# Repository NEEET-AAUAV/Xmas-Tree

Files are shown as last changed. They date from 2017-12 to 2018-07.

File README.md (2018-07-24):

# :christmas_tree: :santa: :christmas_tree: DETI X-mas Tree :christmas_tree: :santa: :christmas_tree:

A **simple** (yet rather cool!) Christmas Tree using LEDs and Printed Circuit Boards.

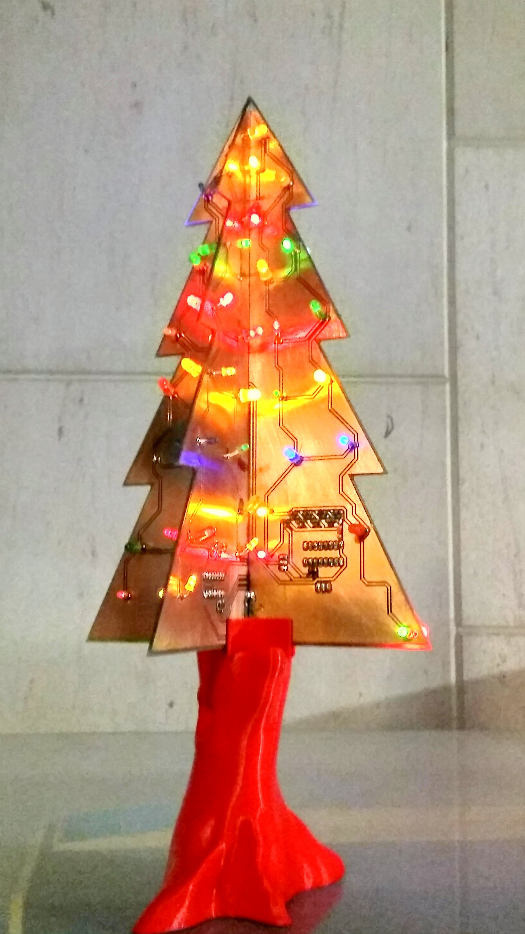
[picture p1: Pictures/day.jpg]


## :gift: List of Material
:snowflake: 64 (or 128) LEDs (_preferably 5mm LEDs_)  
:snowflake: 1 Arduino Nano  
:snowflake: 24 BC557  
:snowflake: 4 JHC138 (or 74HCT138)  
:snowflake: SMD Resistors  
:snowflake: Double Layer Printed Circuit Boards  

## :triangular_ruler: Tree Dimensions
:snowflake:  Approximately an A4 paper sheet

## What we did...
:snowflake: [Arduino Code](Xmas_tree.ino/)  
:snowflake: [Schematic & Board](PCB)  
:snowflake: 3D printed parts: [The Original](https://www.thingiverse.com/thing:537944) and [Our version](https://github.com/NEEET-AAUAV/Xmas-Tree/tree/master/Support)

## How we did it?
The projected electrical circuit is similar to a LED matrix, allowing only one LED ON at any given time.   
To create the illusion of multiple LEDs on, the control algorithm toggles the desired LEDs, one by one, through the decoder hardware at a high frequency, therefore creating the illusion of multiple LEDs being on at the same time.  
A decoder IC is required to control the LEDs independently, enabling the creation of multiple and elaborated animation schemes.  

## Authors
:santa: [André Gradim](https://github.com/a-gradim)  
:santa: [Pedro Martins](https://github.com/k3rn3l-pan1c)  

### Other Elfs worth mention
:snowman: [Hugo Leal](https://github.com/HugoLeal)  
:snowman: [Beatriz Silva](https://github.com/b-dsilva)

--- 

Wanna get in contact?  
Reach us by email: neeetua@gmail.com

---

Created By [NEEET - Núcleo de Estudantes de Eletrónica e Telecomunicações](https://www.facebook.com/neeetaauav/)  
[Department of Electronics, Telecommunications and Informatics](https://www.ua.pt/deti/)  
[University of Aveiro](https://www.ua.pt/)

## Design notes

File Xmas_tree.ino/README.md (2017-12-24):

# Brief Code Documentation

## CONSTANTS
```c
ROW_HOLD_TIME         // Time Interval (us) a Row value cannot change
COLUMN_HOLD_TIME      // Time Interval (us) a Row value cannot change
RND_LED_HOLD_TIME     // Base Time Interval (us) a LED is ON in the Random Mode
SPIRAL_LED_HOLD_TIME  // Time Interval (ms) a LED is ON in the Spiral Mode 
N_PERSIST_ITER        // Number of iterations a LED state persists
```

## Functions
```c
// Implements the Random Generator Algorithm
uint8_t lfsr();

// "moves" the active leds one row up
void ascend();

// "moves" the active leds one row down
void descend();

// Complete sequence: "moves" the active leds up and down across all rows
void ascend_and_descend();

// "moves" the active leds one column clockwise
void clockwise();

// "moves" the active leds one column counter_clockwise
void counter_clockwise();

// "moves" the only active led spirally
// clockwise and then one row down
void spiral_down_clockwise();

// "moves" the only active led spirally
// counter_clockwise and then one row up
void spiral_up_counter_clockwise();

// Blinks all leds
void blink();

/*
 * Random LED Behaviour
 *
 * INPUTS
 *    - n_leds: number of leds to be active during the time interval
 *    - faster: boolean variable that selects the LEDs alternation speed
 *    - scale_factor: increases the time of the function execution
 *
 */
void random_seq(uint8_t n_leds, uint8_t faster, uint8_t scale_factor);

// Abstraction layer for setting rows & columns
void set_columns(uint8_t columns);
void set_rows(uint8_t rows);
```

## Pseudo-Random Algorithm 
The Random Algorithm used to generate the random LEDs sequences is a Linear-feedback shift register (LSFR)   
These pseudo-random algorithm aplies a polynomial transformation to a given seed, through a sequence of XOR operations and bit shifts.
This set of operations results in a new pseudo-random bit that is either retrieved and concatenated to the binary data string  

For more informations, visit the [Wikipedia Page on LSFR](https://en.wikipedia.org/wiki/Linear-feedback_shift_register)

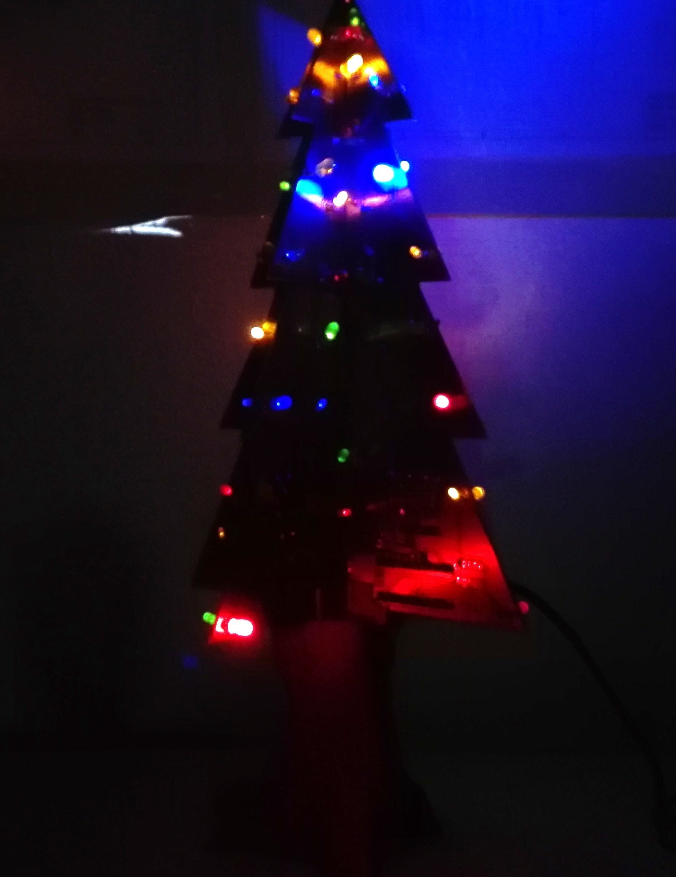
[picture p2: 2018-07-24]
Pictures/night.jpg

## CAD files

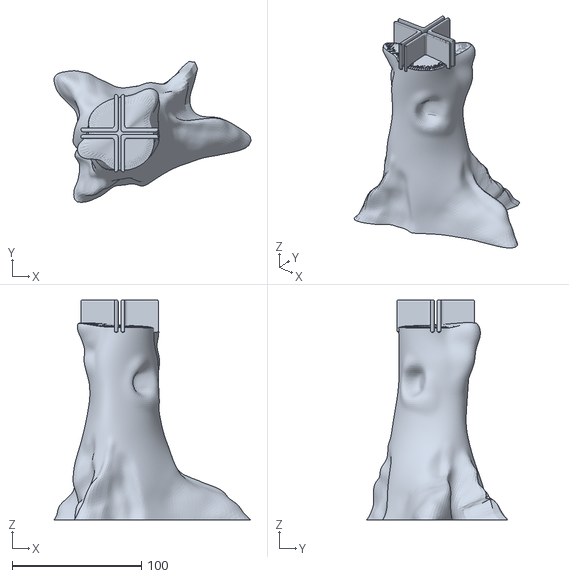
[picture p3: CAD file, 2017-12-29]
Support/base.stl
152.4 x 109.4 x 170.3

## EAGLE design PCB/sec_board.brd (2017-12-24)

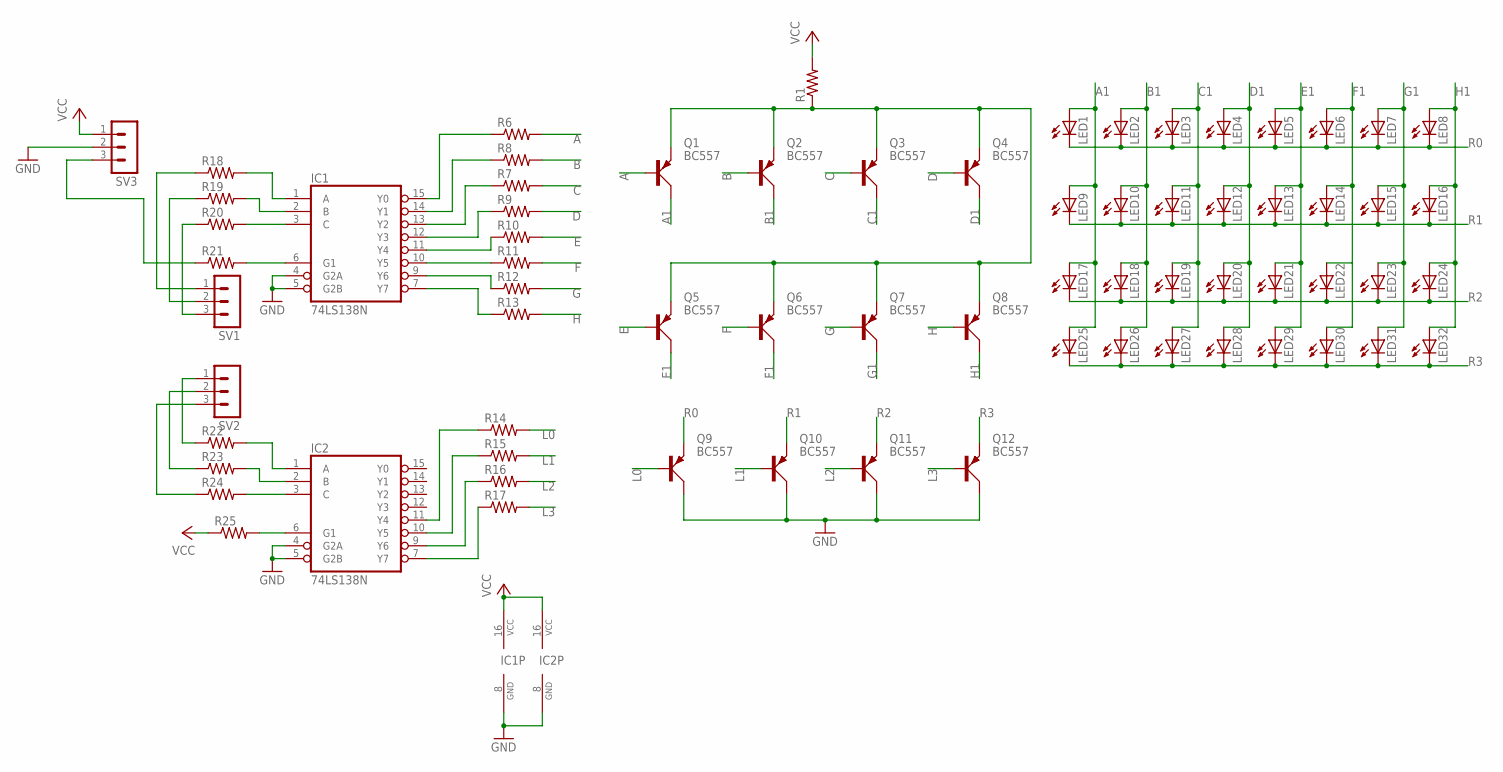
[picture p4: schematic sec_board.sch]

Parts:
IC1, IC2: 74LS138N; DIL16
LED1, LED2, LED3, LED4, LED5, LED6, LED7, LED8, LED9, LED10, LED11, LED12, LED13, LED14, LED15, LED16, LED17, LED18, LED19, LED20, LED21, LED22, LED23, LED24, LED25, LED26, LED27, LED28, LED29, LED30, LED31, LED32: LED5MM
Q1, Q2, Q3, Q4, Q5, Q6, Q7, Q8, Q9, Q10, Q11, Q12: BC557; SOT54A
R1, R6, R7, R8, R9, R10, R11, R12, R13, R14, R15, R16, R17: R-US_R0805; R0805
R18, R19, R20, R21, R22, R23, R24, R25: R-US_M0805; M0805
SV1, SV2, SV3: MA03-1

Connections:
A: Q1.B, R6.2
A1: LED1.A, LED9.A, LED17.A, LED25.A, Q1.C
B: Q2.B, R8.2
B1: LED2.A, LED10.A, LED18.A, LED26.A, Q2.C
C: Q3.B, R7.2
C1: LED3.A, LED11.A, LED19.A, LED27.A, Q3.C
D: Q4.B, R9.2
D1: LED4.A, LED12.A, LED20.A, LED28.A, Q4.C
E: Q5.B, R10.2
E1: LED5.A, LED13.A, LED21.A, LED29.A, Q5.C
F: Q6.B, R11.2
F1: LED6.A, LED14.A, LED22.A, LED30.A, Q6.C
G: Q7.B, R12.2
G1: LED7.A, LED15.A, LED23.A, LED31.A, Q7.C
GND: IC1.4 (G2A), IC1.5 (G2B), IC1.8 (GND), IC2.4 (G2A), IC2.5 (G2B), IC2.8 (GND), Q9.C, Q10.C, Q11.C, Q12.C, SV3.2
H: Q8.B, R13.2
H1: LED8.A, LED16.A, LED24.A, LED32.A, Q8.C
L0: Q9.B, R14.2
L1: Q10.B, R15.2
L2: Q11.B, R16.2
L3: Q12.B, R17.2
unnamed: IC2.7 (Y7), R17.1
unnamed: IC1.15 (Y0), R6.1
unnamed: IC1.14 (Y1), R8.1
unnamed: IC2.9 (Y6), R16.1
unnamed: IC1.13 (Y2), R7.1
unnamed: IC1.12 (Y3), R9.1
unnamed: IC1.11 (Y4), R10.1
unnamed: IC1.10 (Y5), R11.1
unnamed: IC1.9 (Y6), R12.1
unnamed: IC1.7 (Y7), R13.1
unnamed: IC2.10 (Y5), R15.1
unnamed: IC2.11 (Y4), R14.1
unnamed: Q1.E, Q2.E, Q3.E, Q4.E, Q5.E, Q6.E, Q7.E, Q8.E, R1.1
unnamed: R24.1, SV2.3
unnamed: R23.1, SV2.2
unnamed: R22.1, SV2.1
unnamed: R20.1, SV1.3
unnamed: R19.1, SV1.2
unnamed: R18.1, SV1.1
unnamed: R21.1, SV3.3
unnamed: IC2.3 (C), R24.2
unnamed: IC2.2 (B), R23.2
unnamed: IC2.1 (A), R22.2
unnamed: IC1.3 (C), R20.2
unnamed: IC1.2 (B), R19.2
unnamed: IC1.1 (A), R18.2
unnamed: IC1.6 (G1), R21.2
unnamed: IC2.6 (G1), R25.2
R0: LED1.K (C), LED2.K (C), LED3.K (C), LED4.K (C), LED5.K (C), LED6.K (C), LED7.K (C), LED8.K (C), Q9.E
R1: LED9.K (C), LED10.K (C), LED11.K (C), LED12.K (C), LED13.K (C), LED14.K (C), LED15.K (C), LED16.K (C), Q10.E
R2: LED17.K (C), LED18.K (C), LED19.K (C), LED20.K (C), LED21.K (C), LED22.K (C), LED23.K (C), LED24.K (C), Q11.E
R3: LED25.K (C), LED26.K (C), LED27.K (C), LED28.K (C), LED29.K (C), LED30.K (C), LED31.K (C), LED32.K (C), Q12.E
VCC: IC1.16 (VCC), IC2.16 (VCC), R1.2, R25.1, SV3.1

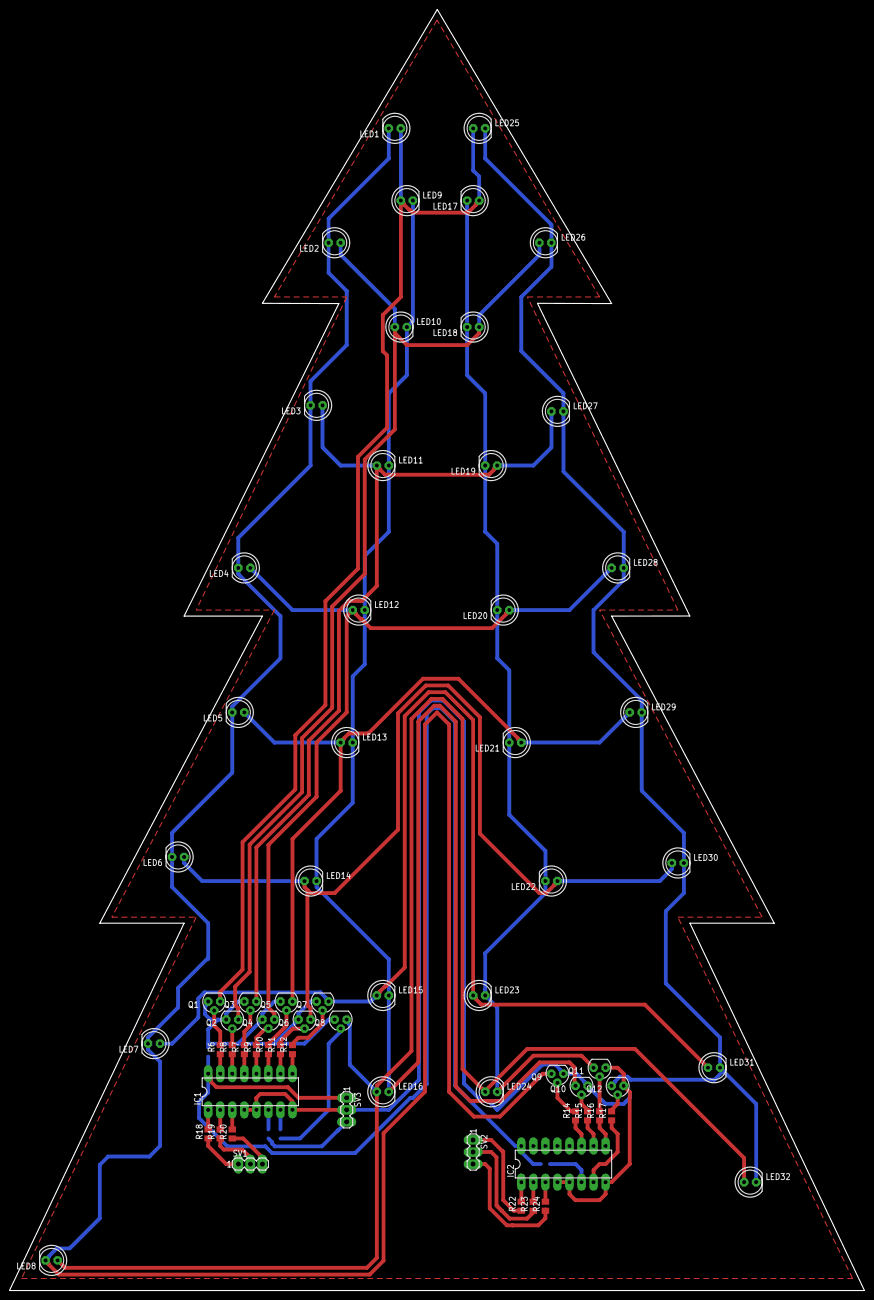
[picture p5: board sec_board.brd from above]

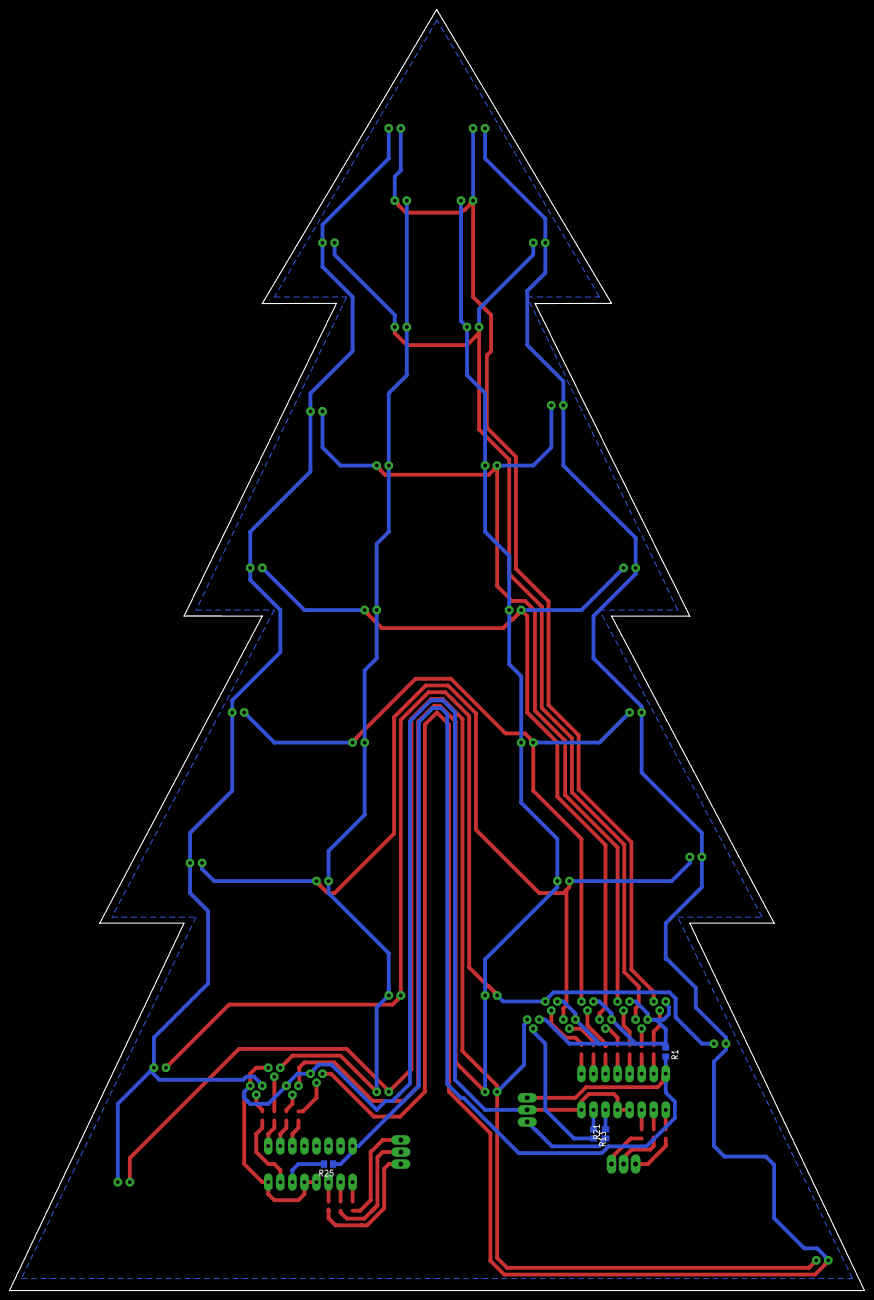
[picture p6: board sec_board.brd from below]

Board: 2 copper layers, 180.3 x 270.2 mm, 70 parts (4 on the bottom side), 54 nets.

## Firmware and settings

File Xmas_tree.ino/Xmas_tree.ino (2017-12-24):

/*
                                                                      ,----,
                                                                    ,/   .`|
 ,--,     ,--,           ____                                     ,`   .'  :
 |'. \   / .`|         ,'  , `.                                 ;    ;     /
 ; \ `\ /' / ;      ,-+-,.' _ |                               .'___,/    ,' __  ,-.
 `. \  /  / .'   ,-+-. ;   , ||             .--.--.           |    :     |,' ,'/ /|
  \  \/  / ./   ,--.'|'   |  || ,--.--.    /  /    '          ;    |.';  ;'  | |' | ,---.     ,---.
   \  \.'  /   |   |  ,', |  |,/       \  |  :  /`./          `----'  |  ||  |   ,'/     \   /     \
    \  ;  ;    |   | /  | |--'.--.  .-. | |  :  ;_                '   :  ;'  :  / /    /  | /    /  |
   / \  \  \   |   : |  | ,    \__\/: . .  \  \    `.             |   |  '|  | ' .    ' / |.    ' / |
  ;  /\  \  \  |   : |  |/     ," .--.; |   `----.   \            '   :  |;  : | '   ;   /|'   ;   /|
./__;  \  ;  \ |   | |`-'     /  /  ,.  |  /  /`--'  /            ;   |.' |  , ; '   |  / |'   |  / |
|   : / \  \  ;|   ;/        ;  :   .'   \'--'.     /             '---'    ---'  |   :    ||   :    |
;   |/   \  ' |'---'         |  ,     .-./  `--'---'                              \   \  /  \   \  /
`---'     `--`                `--`---'                                             `----'    `----'

                                                   ,----,
         ,--.                                    ,/   .`|
       ,--.'|    ,---,.    ,---,.    ,---,.    ,`   .'  :
   ,--,:  : |  ,'  .' |  ,'  .' |  ,'  .' |  ;    ;     /
,`--.'`|  ' :,---.'   |,---.'   |,---.'   |.'___,/    ,'
|   :  :  | ||   |   .'|   |   .'|   |   .'|    :     |
:   |   \ | ::   :  |-,:   :  |-,:   :  |-,;    |.';  ;
|   : '  '; |:   |  ;/|:   |  ;/|:   |  ;/|`----'  |  |
'   ' ;.    ;|   :   .'|   :   .'|   :   .'    '   :  ;
|   | | \   ||   |  |-,|   |  |-,|   |  |-,    |   |  '
'   : |  ; .''   :  ;/|'   :  ;/|'   :  ;/|    '   :  |
|   | '`--'  |   |    \|   |    \|   |    \    ;   |.'
'   : |      |   :   .'|   :   .'|   :   .'    '---'
;   |.'      |   | ,'  |   | ,'  |   | ,'
'---'        `----'    `----'    `----'


Project and designed by
* André Gradim
* Pedro Martins

With the helping of:
* Hugo Leal
* Beatriz Silva

NEEET 2017-18
*/


// MACROS
#define vector_len(X) (sizeof(X) / sizeof(X[0]))
#define ENABLE_DECODERS() digitalWrite(11, HIGH)
#define DISABLE_DECODERS() digitalWrite(11, LOW)

// TIMES
#define ROW_HOLD_TIME 250        // us
#define COLUMN_HOLD_TIME 400     // us
#define RND_LED_HOLD_TIME 300    // us
#define SPIRAL_LED_HOLD_TIME 30  // ms
#define N_PERSIST_ITER 500

// TREE CONSTANTS
#define MAX_ROWS 8
#define MAX_COLUMNS 8

// RANDOM CONSTANTS
#define FASTER_RND_SEQ 1
#define SLOWER_RND_SEQ 0




/*
 *  FUNCTION HEADERS DECLARATION
 */
uint8_t lfsr();
void ascend();
void descend();
void ascend_and_descend();
void clockwise();
void counter_clockwise();
void set_columns(uint8_t columns);
void set_rows(uint8_t rows);
void blink();
void random_seq(uint8_t n_leds, uint8_t faster, uint8_t scale_factor);
void spiral_down_clockwise();
void spiral_up_counter_clockwise();

/*
 *  VARIABLE DECLARATION
 */
// mapping real column order with decoder outputs
uint8_t colums_order[12] = {0, 1, 2, 4, 2, 5, 3, 5, 6, 7, 6, 1};
uint8_t rows_order[8] = {0, 1, 2, 3, 4, 5, 6, 7};

// counters
uint8_t columns = 0x00;
uint8_t rows = 0x00;

uint8_t flag = 0;
uint8_t flag_counter = 0;



/*
 *  PINOUT CONFIGURATION
 */

void setup() {
  // Enable Decoder
  pinMode(11, OUTPUT);      // D11

  // CONTROL  IC1
  pinMode(7, OUTPUT);       // D7
  pinMode(6, OUTPUT);       // D6
  pinMode(5, OUTPUT);       // D5

  // CONTROL  IC2
  pinMode(4, OUTPUT);       // D4
  pinMode(3, OUTPUT);       // D3
  pinMode(2, OUTPUT);       // D2
}


void loop() {
  uint8_t k;
  ENABLE_DECODERS();

  while(true)
  {
    for(k = 0; k < 1*2*MAX_ROWS; k++)
    {
      ascend_and_descend();
    }
    for(k = 0; k < 2; k++)
    {
      spiral_down_clockwise();
    }
    for(k = 0; k < 60; k++)
    {
      random_seq(13, SLOWER_RND_SEQ, 2);
    }
    for(k = 0; k < 2*MAX_COLUMNS; k++)
    {
      clockwise();
    }
    for(k = 0; k < 200; k++)
    {
      random_seq(4, FASTER_RND_SEQ, 1);
    }
    for(k = 0; k < 3*MAX_COLUMNS; k++)
    {
      counter_clockwise();
    }
    for(k = 0; k < 90; k++)
    {
      random_seq(7, FASTER_RND_SEQ, 10);
    }
    for(uint8_t k = 0; k < 4*2*MAX_ROWS; k++)
    {
      ascend_and_descend();
    }
    for(k = 0; k < 130; k++)
    {
      random_seq(20, SLOWER_RND_SEQ, 4);
    }
    for(k = 0; k < 3; k++)
    {
      spiral_up_counter_clockwise();
    }
    for(k = 0; k < 2*MAX_COLUMNS; k++)
    {
      clockwise();
    }
    for(k = 0; k < 2*MAX_COLUMNS; k++)
    {
      counter_clockwise();
    }
    for(k = 0; k < 2*MAX_ROWS; k++)
    {
      descend();
    }
    for(k = 0; k < 80; k++)
    {
      random_seq(4, FASTER_RND_SEQ, 1);
    }
    for(k = 0; k < MAX_ROWS; k++)
    {
      ascend();
    }
    spiral_down_clockwise();
    //blink();
  }
}


/*
 * Linear-feedback shift register algorithm
 * Feedback polynomial: x^16 + x^15 + x^13 + x^9 + x^6 + x^4 + x^2 + 1
 *
 * Returns a random bit (0, 1)
 *
 */
uint8_t lfsr(){
  static uint16_t seed = 0xACE1;
  static uint16_t rndNum = seed;

  uint8_t rndBit = ((rndNum >> 0) ^ (rndNum >> 1) ^ (rndNum >> 3) ^ (rndNum >> 7) ^ (rndNum >> 10) ^ (rndNum >> 12) ^ (rndNum >> 14)) & 1;
  rndNum = (rndNum >> 1) | (rndBit << 15);

  return rndBit;
}

// "moves" the active leds one row up
void ascend(){
      set_rows(rows);
      for(int k = 0, columns = 0; k < N_PERSIST_ITER; k++, columns++)
      {
        set_columns(columns);
        columns = (columns == vector_len(colums_order) ? 0 : columns);
        delayMicroseconds(ROW_HOLD_TIME);
      }
      rows = (rows == MAX_ROWS ? 0 : --rows);
}

// "moves" the active leds one row down
void descend(){
      set_rows(rows);
      for(int k = 0, columns = vector_len(colums_order); k < N_PERSIST_ITER; k++, columns--)
      {
        set_columns(columns);
        columns = (columns == 0 ? vector_len(colums_order) : columns);
        delayMicroseconds(ROW_HOLD_TIME);
      }
      rows = (rows == MAX_ROWS ? 0 : ++rows);
}

// Complete sequence: "moves" the active leds up and down across all rows
void ascend_and_descend(){
  flag == 1 ? descend() : ascend();

  if(flag_counter == 7)
  {
    flag = !flag;
    flag_counter = 0;
  }
  flag_counter++;
}

// "moves" the active leds one column clockwise
void clockwise(){
  set_columns(columns);
  for(int k = 0, rows = 0; k < N_PERSIST_ITER; k++, rows++)
  {
    set_rows(rows);
    rows = (rows == MAX_ROWS ? 0 : rows);
    delayMicroseconds(COLUMN_HOLD_TIME);
  }
  columns = (columns == vector_len(colums_order) ? 0 : ++columns);
}

// "moves" the active leds one column counter_clockwise
void counter_clockwise(){
  set_columns(columns);
  for(int k = 0, rows = 0; k < N_PERSIST_ITER; k++, rows++)
  {
    set_rows(rows);
    rows = (rows == MAX_ROWS ? 0 : rows);
    delayMicroseconds(COLUMN_HOLD_TIME);
  }
  columns = (columns == 0 ? vector_len(colums_order) : --columns);
}

// "moves" the only active led spirally
// clockwise and then one row down
void spiral_down_clockwise(){
  for(uint8_t k = 0, rows = 0; k < MAX_ROWS; k++, rows++)
  {
    set_rows(rows);
    for(uint8_t m = 0, columns = 0; m < vector_len(colums_order); m++, columns++)
    {
      set_columns(columns);
      columns = (columns == vector_len(colums_order) ? 0 : columns);
      delay(SPIRAL_LED_HOLD_TIME);
    }
  }
}

// "moves" the only active led spirally
// counter_clockwise and then one row up
void spiral_up_counter_clockwise(){
  for(uint8_t k = (MAX_ROWS-1), rows = (MAX_ROWS-1); k > 0; k--, rows--)
  {
    set_rows(rows);
    for(uint8_t m = 0, columns = 0; m < vector_len(colums_order); m++, columns--)
    {
      set_columns(columns);
      columns = (columns == 0 ? vector_len(colums_order) : columns);
      delay(SPIRAL_LED_HOLD_TIME);
    }
  }
}

// Blinks all leds
void blink(){

  for(int r = 0, rows = 0; r < N_PERSIST_ITER; r++, rows++)
  {
    set_rows(rows);
    for(int c = 0, columns = 0; c < N_PERSIST_ITER; c++, columns++)
    {
      set_columns(columns);
      columns = (columns == vector_len(colums_order) ? 0 : columns);
    }
    rows = (rows == MAX_ROWS ? 0 : rows);
  }
  DISABLE_DECODERS();
  delay(1000);
  ENABLE_DECODERS();
}

/*
 * Random LED Behaviour
 *
 * INPUTS
 *    - n_leds: number of leds to be active during the time interval
 *    - faster: boolean variable that selects the LEDs alternation speed
 *    - scale_factor: increases the time of the function execution
 *
 */
void random_seq(uint8_t n_leds, uint8_t faster, uint8_t scale_factor){
    uint8_t leds_seq[n_leds];
    for(uint8_t k = 0; k < n_leds; k++)
    {
      leds_seq[k] = ( (lfsr()) << 7 ) | ( (lfsr()) << 6 ) | ( (lfsr()) << 5 ) | \
                    ( (lfsr()) << 2 ) | ( (lfsr()) << 1 ) | ( lfsr() );
    }

    for(int m = 0; m < N_PERSIST_ITER; m++)
    {
      for(int k = 0; k < n_leds; k++)
      {
        columns = leds_seq[k] & 0b00000111;
        rows    = (leds_seq[k] & 0b11100000) >> 5;
        set_columns(columns);
        set_rows(rows);
        if(!faster) delayMicroseconds(RND_LED_HOLD_TIME / scale_factor);
      }
      if(faster) delayMicroseconds(RND_LED_HOLD_TIME / scale_factor);
    }
}

/*
 * Abstraction layer for setting rows & columns
 *
 */
void set_columns(uint8_t columns)
{
  digitalWrite(4, colums_order[columns] & 0x01);
  digitalWrite(3, colums_order[columns] & 0x02);
  digitalWrite(2, colums_order[columns] & 0x04);
}

void set_rows(uint8_t rows)
{
  digitalWrite(7, rows & 0x01);
  digitalWrite(6, rows & 0x02);
  digitalWrite(5, rows & 0x04);
}

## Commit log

2017-12-24 Final version of the Arduino Code
2017-12-24 PCB - Schematic and board
    [main_board.brd, main_board.sch, sec_board.brd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]
2017-12-29 Added support stl
    [base.stl]

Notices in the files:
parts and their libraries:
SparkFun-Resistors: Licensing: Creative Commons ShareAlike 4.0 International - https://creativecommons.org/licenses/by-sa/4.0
